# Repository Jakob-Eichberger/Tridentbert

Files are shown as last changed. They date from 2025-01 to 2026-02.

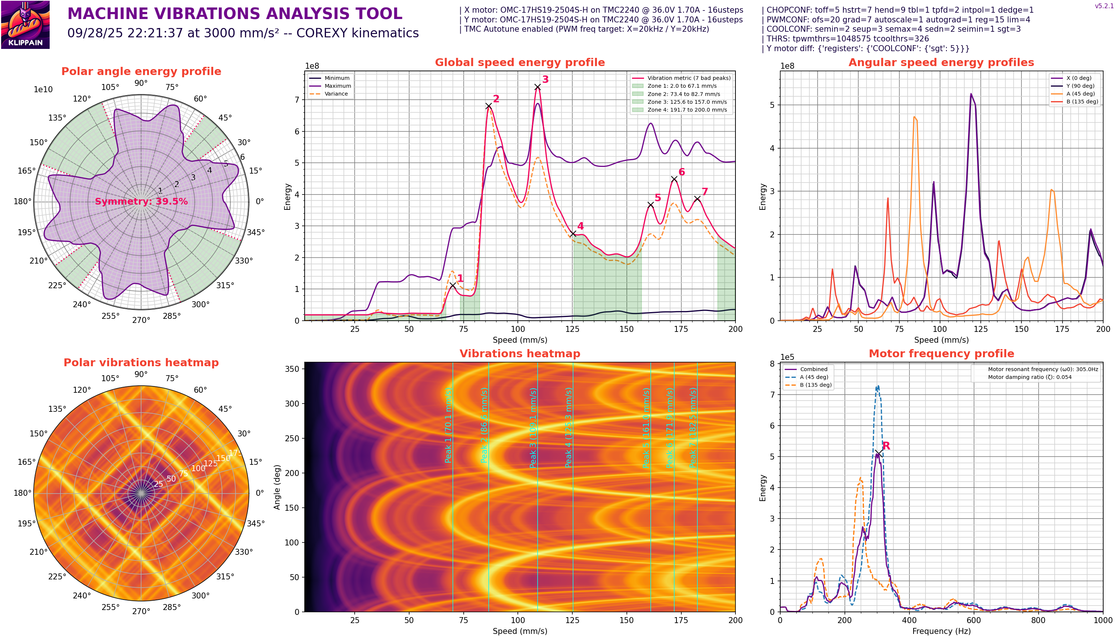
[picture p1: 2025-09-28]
ShakeTune_results/vibrations/vibrationsprofile_20250928_222136.png

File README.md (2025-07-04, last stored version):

# Tridentbert
Tridentbert is my take on a 300 x 300 x 250mm Voron Trident, a popular open source diy 3d printer, changed with all the best mods making this one of the most capable 3d printer on the market today.



# Improvements over a stock Voron Trident
> [!CAUTION]
> This design is based on and will only work with Takeoff toolhead and Chube hotend. This is because of the changed gantry height so that Takeoff wont hit one of the z leadscrews.
> **Using a more standard Voron toolhead might result in the nozzle not beeing able to reach the bed!**

* 4040 based 20 extrusions for increased frame rigidity, which helps when printing at high speed and with high belt tension.
* 6mm aluminium panels all around the machine, to increase rigidity even more.
* Monolith 9mm AWD sheet metal gantry, which is the best gantry design currently on the market.
* Using Takeoff toolhead with Chube, Beacon probe and a CNC Sherpa Mini extruder from Fystec for maximum extrusion performance.
* Z stepper motors mounted directly to the bottom aluminum panel for easy mounting.
* Electronics are mounted on the side for super easy maintenance.

# License
Since this printers frame is derived from a Voron Trident, the Voron Trident License applies to the frame only. The panels and electronics sidepack are off my own design and are licensed under `Attribution-NonCommercial-ShareAlike 4.0 International`. This project does not alter nor try to alter the licencse of used mods.
* Monolith gantry: https://github.com/CloakedWayne/Monolith_Gantry_V2-VT?tab=License-1-ov-file#readme
* Takeoff toolhead: https://github.com/Kizime123/Takeoff-Toolhead?tab=GPL-3.0-1-ov-file#readme
* Voron Trident: https://github.com/VoronDesign/Voron-Trident

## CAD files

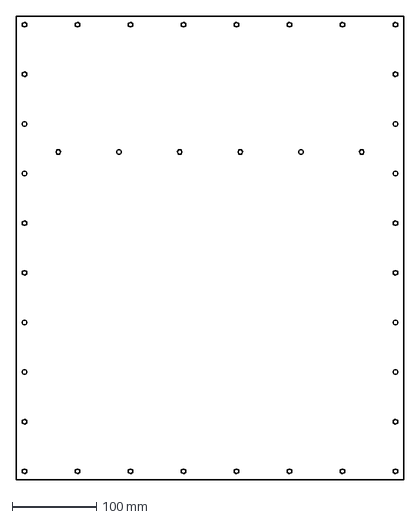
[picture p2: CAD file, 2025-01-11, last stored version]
DXF/Panel_Side.dxf
460.0 x 550.0 mm

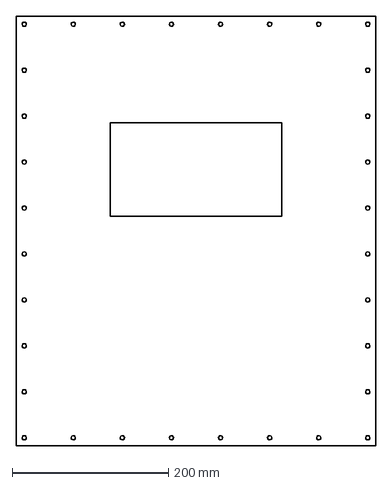
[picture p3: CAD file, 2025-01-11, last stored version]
DXF/Panel_Door.dxf
460.0 x 550.0 mm

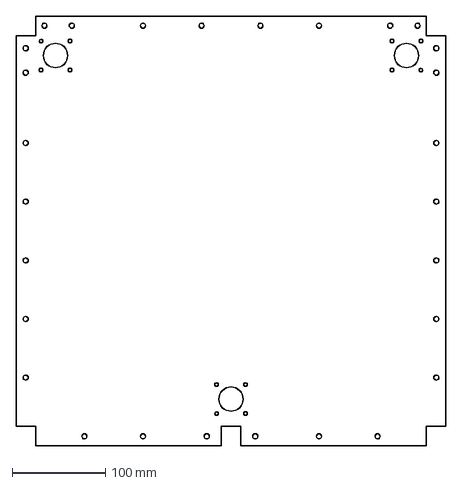
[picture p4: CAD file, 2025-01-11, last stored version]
DXF/Panel_Bottom.dxf
460.0 x 460.0 mm

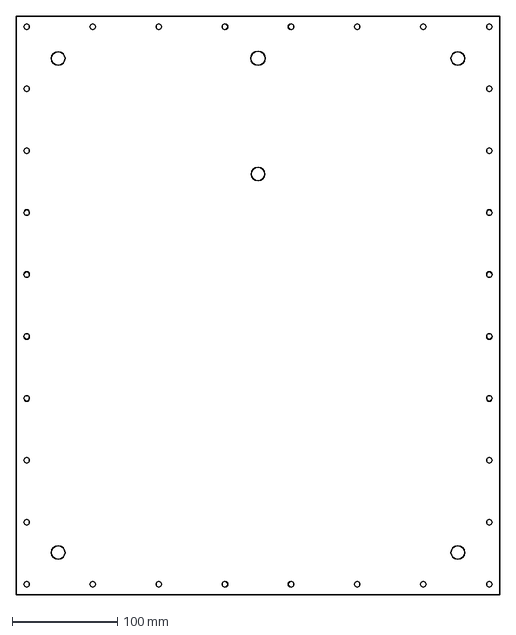
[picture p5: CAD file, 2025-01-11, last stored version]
DXF/Panel_Back.dxf
460.0 x 550.0 mm

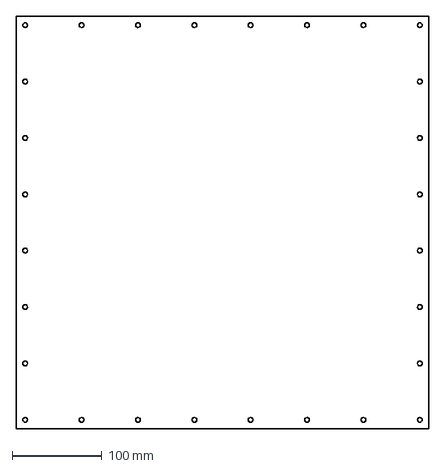
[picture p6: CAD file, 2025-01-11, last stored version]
DXF/Panel_Top.dxf
460.0 x 460.0 mm

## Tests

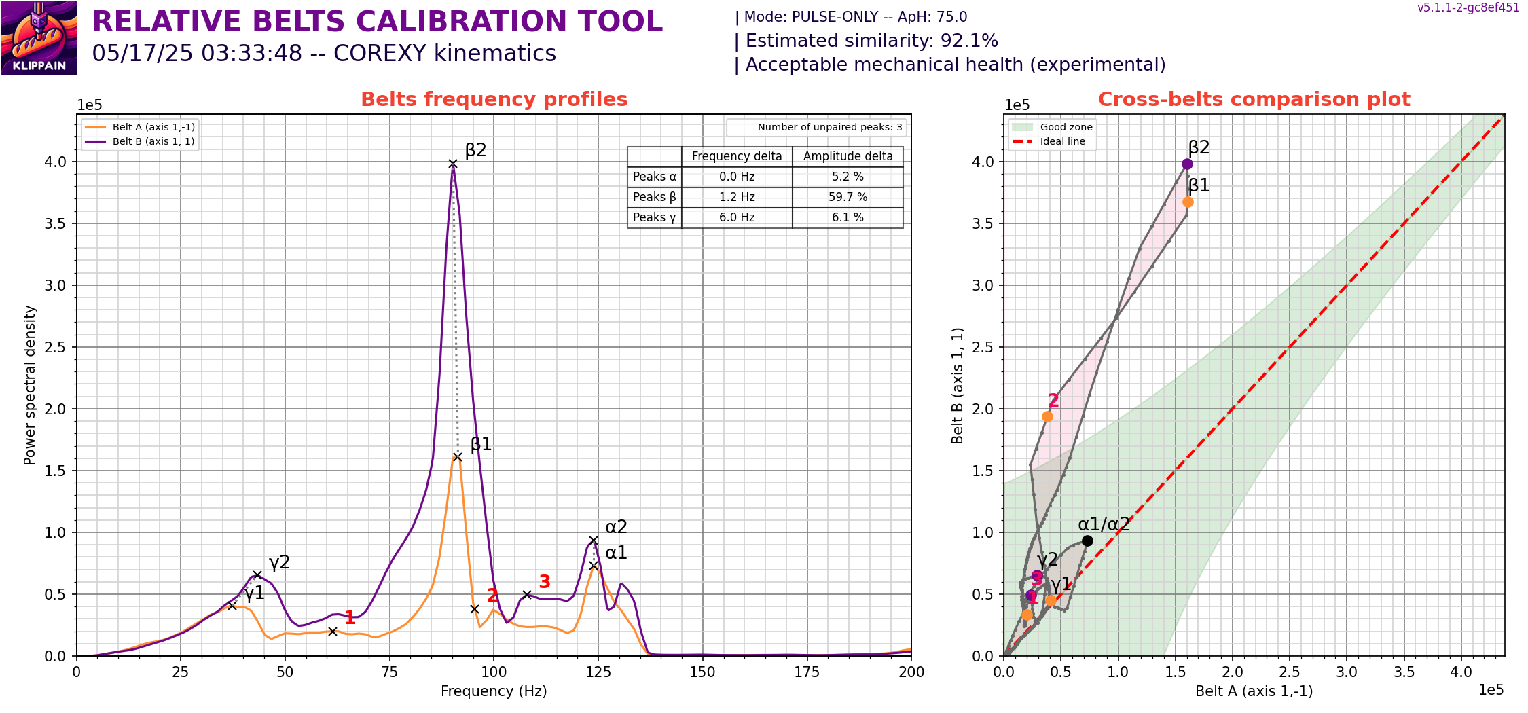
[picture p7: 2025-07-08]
ShakeTune_results/belts/beltscomparison_20250517_033347.png

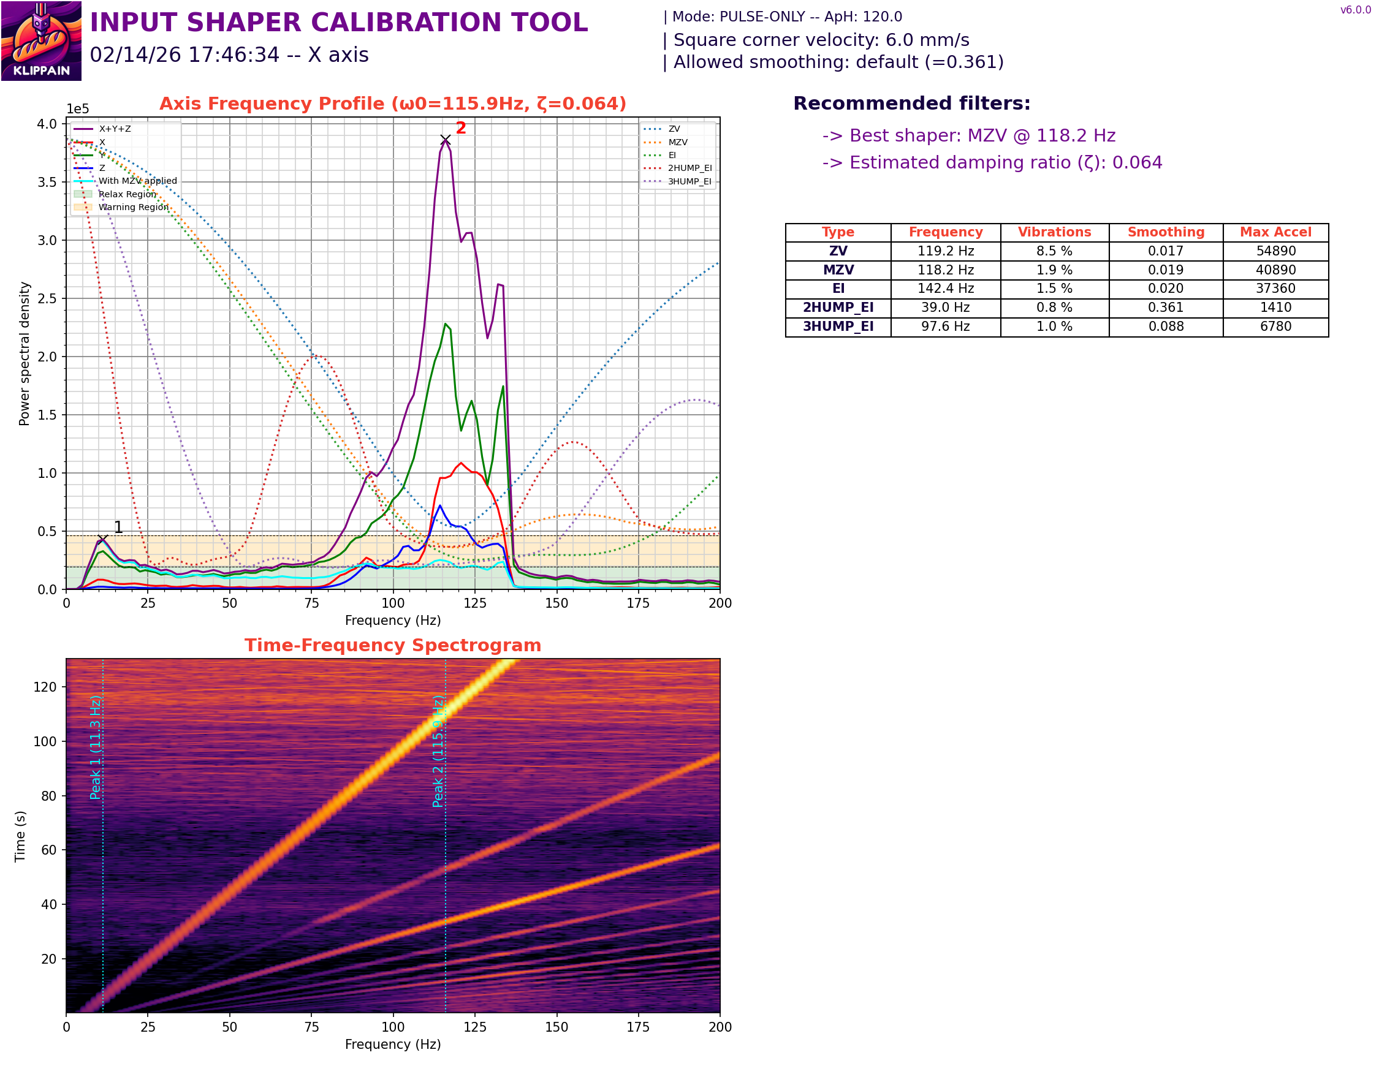
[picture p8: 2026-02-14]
ShakeTune_results/input_shaper/inputshaper_20260214_174632_axis_X.png

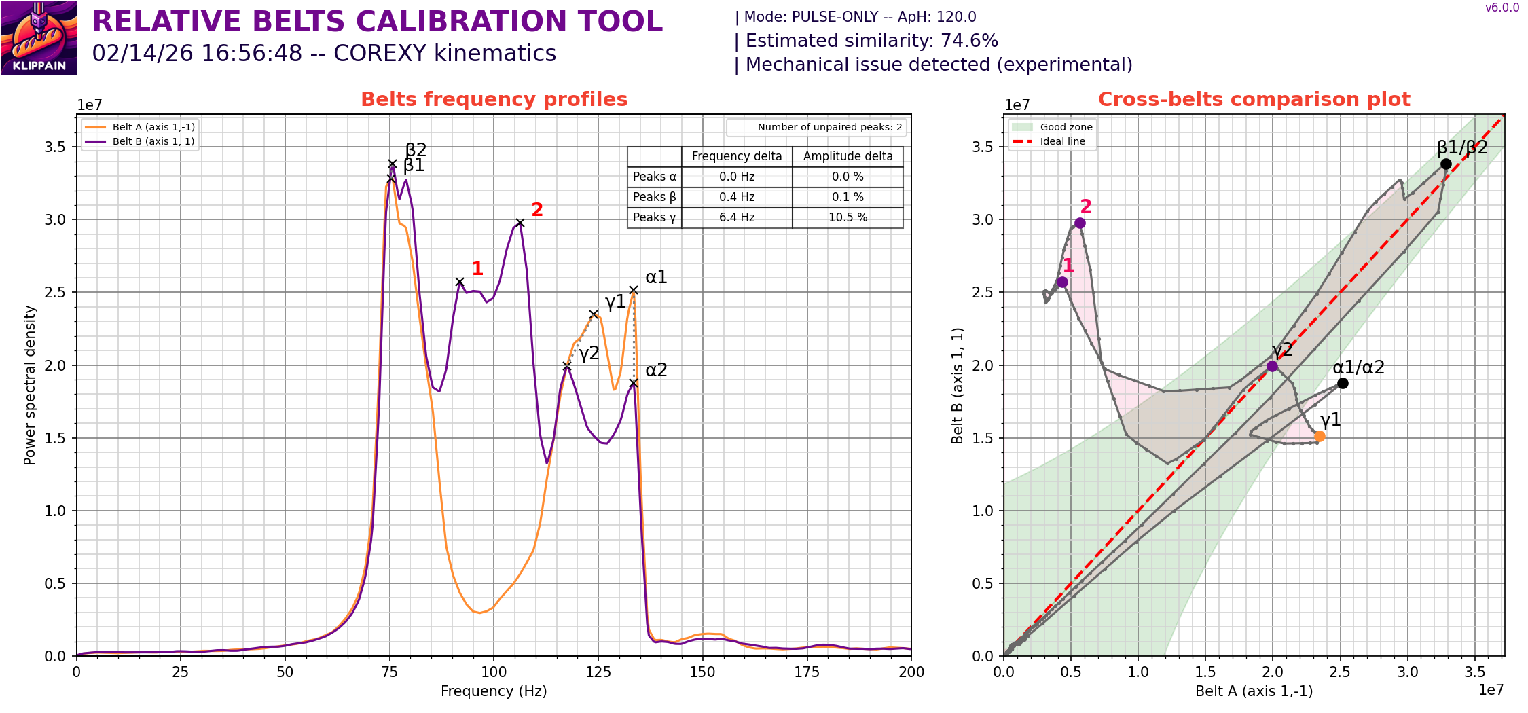
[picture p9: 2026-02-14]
ShakeTune_results/belts/beltscomparison_20260214_165647.png

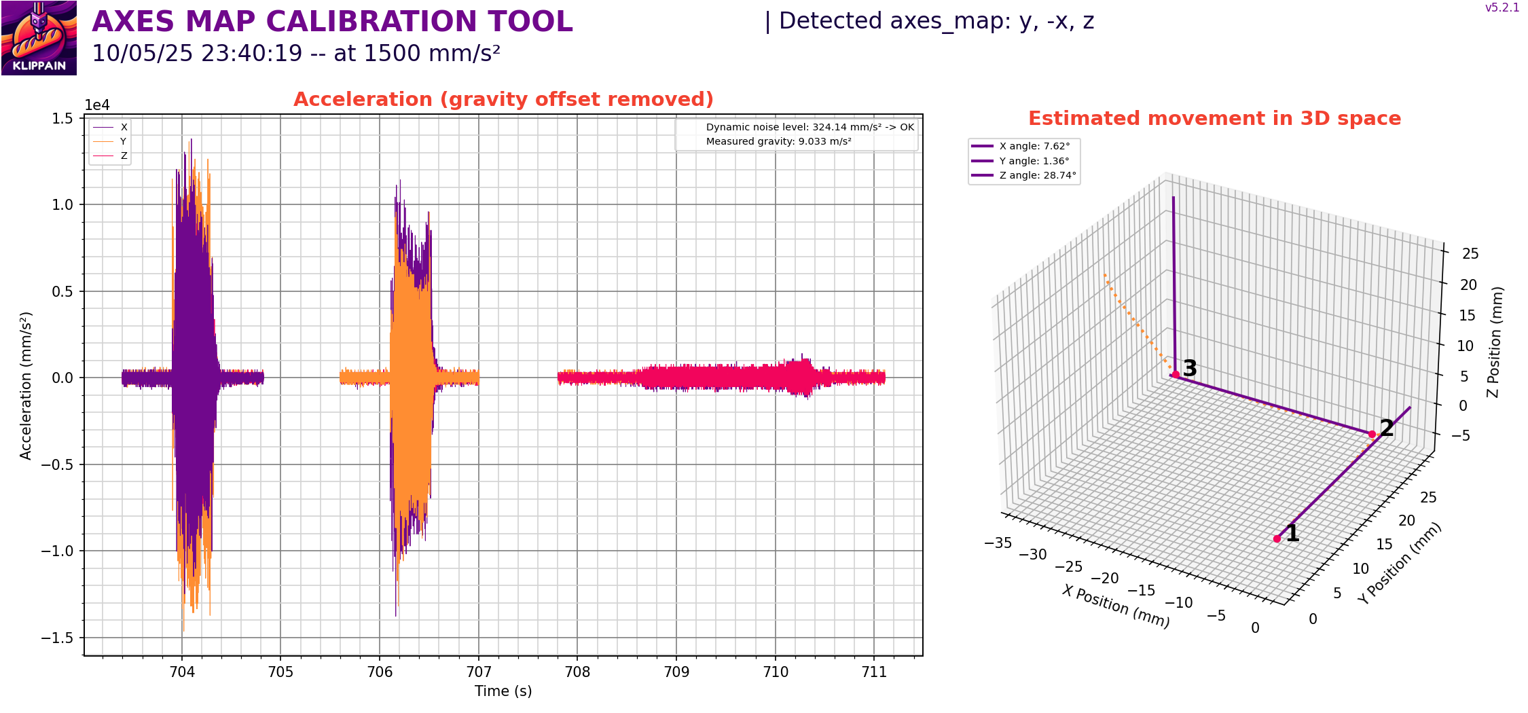
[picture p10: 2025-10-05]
ShakeTune_results/axes_map/axesmap_20251005_234019.png

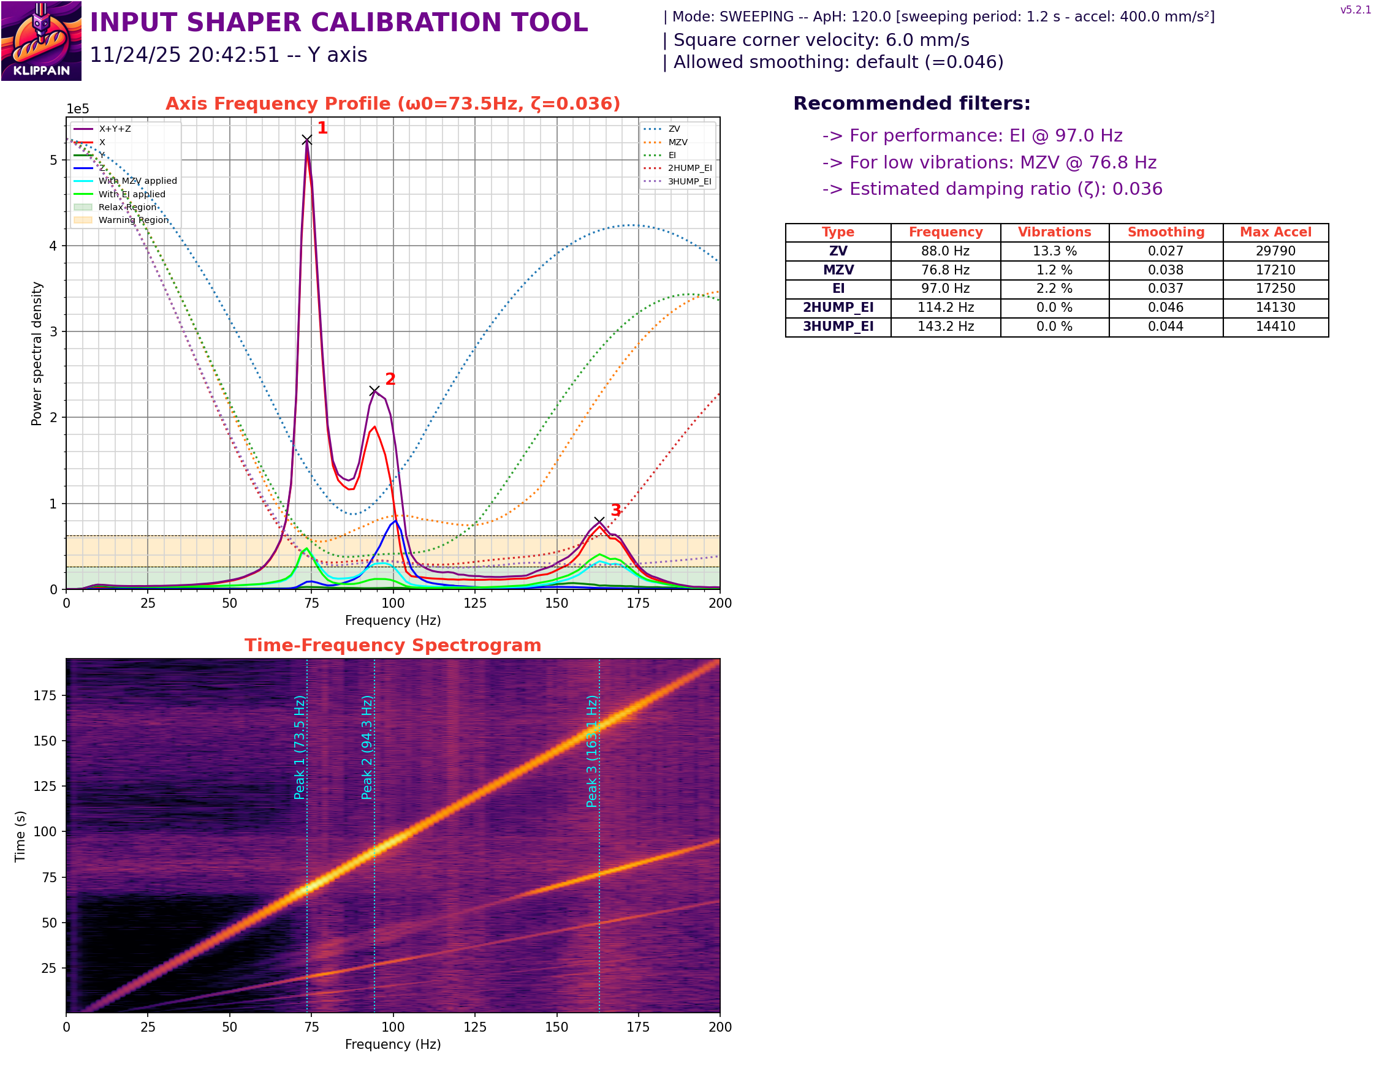
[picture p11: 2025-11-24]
ShakeTune_results/input_shaper/inputshaper_20251124_203850_axis_Y.png

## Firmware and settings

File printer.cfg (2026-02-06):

#[include mainsail.cfg]
[include macro.cfg]
[include Line_Purge.cfg]
[include KAMP_Settings.cfg]
[include Smart_Park.cfg]
[include TEST_SPEED.cfg]
[include config_backup.cfg]
[include macro_thermal_expansion_compensation.cfg]
[mcu]
serial: /dev/serial/by-id/usb-Klipper_stm32f446xx_440035001550535556323420-if00
restart_method: command

[mcu therm]
serial: /dev/serial/by-id/usb-Klipper_stm32f042x6_048021000F4330344E333720-if00
restart_method: command
#####################################################################
#   Extruder
#####################################################################

[virtual_sdcard]
path: ~/printer_data/gcodes
on_error_gcode: CANCEL_PRINT

[pause_resume]

[display_status]

[respond]

[auto_speed]

[save_variables]
filename: ~/printer_data/config/variables.txt

[printer]
kinematics: corexy
max_velocity: 600
max_accel: 20000
max_z_velocity: 15
max_z_accel: 45
square_corner_velocity: 6.0

[extruder]
enable_pin: !PE0
step_pin: PE6
dir_pin: PA14                                                      # Add ! if moving opposite direction
full_steps_per_rotation: 200                                       # Set to 200 for LDO 1.8° stepper motor, and set to 400 for OMC(StepperOnline) 0.9° stepper motor

#wwbmg
rotation_distance:  22.23
gear_ratio: 50:10

#G2A
#rotation_distance:  47.088                                           # See calibrating rotation_distance on extruders doc
#gear_ratio: 9:1                                                    # For Mini Afterburner

microsteps: 16


nozzle_diameter: 0.500
filament_diameter: 1.750

heater_pin: PA2                                                  
sensor_type: PT1000    

sensor_pin: therm:PA5
min_temp: 0
max_temp: 500
min_extrude_temp: 170
max_extrude_only_distance: 300
pressure_advance: 0.028
pressure_advance_smooth_time: 0.020000
max_extrude_cross_section: 50

#heater_power: 120
# MPC settings
#control: mpc
#cooling_fan: fan
#filament_diameter: 1.75
#filament_density: 1.20
#filament_heat_capacity: 1.8 

#control: pid
#pid_kp: 55.642
#pid_ki: 3.041
#pid_kd: 254.560
#pid_version: 1
#pid_target: 105.00
#pid_tolerance: 0.0200

#[verify_heater extruder]
#max_error: 120 # double if needed
#check_gain_time: 60 #default for extruder is 20, 60 for bed heater. increase for weak heaters. 
#hysteresis: 5 #default is 5, this is the maximum allowable deviation from setpoint. increase during PID tuning. 
#heating_gain: 1.5 #default is 2. increase this for very fast heaters, decrease this for weak ones.

[tmc2240 extruder]
cs_pin: PD3
spi_bus: spi1
interpolate: False
run_current: 0.6
stealthchop_threshold: 0       
rref: 12000

#####################################################################
#   Motors
#####################################################################

# Driver3
[stepper_x1]
enable_pin: !PA0
step_pin: PG4
dir_pin: PC1
microsteps: 16
rotation_distance: 40

[tmc2240 stepper_x1]
cs_pin: PC7
spi_bus: spi1
rref: 12000
run_current: 1.7
stealthchop_threshold: 0


# Driver4
[stepper_x]
enable_pin: !PG2
step_pin: PF9
dir_pin: PF10
microsteps: 16
rotation_distance: 40

endstop_pin: tmc2240_stepper_x:virtual_endstop
position_endstop: 300
position_max: 300
homing_speed: 100
homing_retract_dist: 200
min_home_dist: 40
homing_positive_dir: true
use_sensorless_homing: true

[tmc2240 stepper_x]
cs_pin: PF2
spi_bus: spi1
rref: 12000
stealthchop_threshold: 0
run_current: 1.7

home_current: 0.5
diag0_pin: ^!PG12
#driver_SGT: 3

# Driver5
[stepper_y1]
enable_pin: !PF1
step_pin: PC13
dir_pin: PF0
microsteps: 16
rotation_distance: 40

[tmc2240 stepper_y1]
cs_pin: PE4
spi_bus: spi1
rref: 12000
stealthchop_threshold: 0
run_current: 1.7


# Driver6
[stepper_y] 
enable_pin: !PD4
step_pin: PE2
dir_pin: PE3
microsteps: 16
rotation_distance: 40
endstop_pin: tmc2240_stepper_y:virtual_endstop
position_endstop: 267
position_max: 267
homing_speed: 100
homing_retract_dist: 60
min_home_dist: 40
homing_positive_dir: true
use_sensorless_homing: true

[tmc2240 stepper_y]
cs_pin: PE1
spi_bus: spi1
rref: 12000
stealthchop_threshold: 0
run_current: 1.7

home_current: 0.5
diag0_pin: ^!PG14
#driver_SGT: 3

# Driver0
[stepper_z]
enable_pin: !PF14
step_pin: PF13
dir_pin: !PF12
microsteps: 16
rotation_distance: 8
endstop_pin: PG10
position_endstop: 00
position_max: 250
position_min: -5

[tmc2240 stepper_z]
cs_pin: PC4
spi_bus: spi1
rref: 12000
stealthchop_threshold: 999999
run_current: 0.800

# Driver1
[stepper_z1]
enable_pin: !PF15
step_pin: PG0
dir_pin: !PG1
microsteps: 16
rotation_distance: 8
endstop_pin: PG10

[tmc2240 stepper_z1]
cs_pin: PD11
spi_bus: spi1
rref: 12000
stealthchop_threshold: 999999
run_current: 0.800

# Driver2
[stepper_z2]
enable_pin: !PG5
step_pin: PF11
dir_pin: !PG3
microsteps: 16
rotation_distance: 8

[tmc2240 stepper_z2]
cs_pin: PC6
spi_bus: spi1
rref: 12000
stealthchop_threshold: 999999
run_current: 0.800

[autotune_tmc stepper_x]
motor: omc-17hs19-2504s-h
sgt: 4
voltage: 36

[autotune_tmc stepper_x1]
motor: omc-17hs19-2504s-h
voltage: 36

[autotune_tmc stepper_y]
motor: omc-17hs19-2504s-h
sgt: 5
voltage: 36

[autotune_tmc stepper_y1]
motor: omc-17hs19-2504s-h
voltage: 35

#####################################################################
#   Bed Mesh + Probe
#####################################################################

[beacon]
serial: /dev/serial/by-id/usb-Beacon_Beacon_RevH_7A4B73935154354D38202020FF0A1731-if00
is_non_critical: True
home_method: contact
home_method_when_homed: contact
home_autocalibrate: unhomed
x_offset: -23
y_offset: 0
mesh_main_direction: x
mesh_runs: 2
speed: 3000
lift_speed: 250
home_xy_position: 140,140 ; Also change the position in zero_reference_position
home_xy_move_speed: 300
home_z_hop_speed: 50
home_z_hop: 15
home_y_before_x: true
contact_max_hotend_temperature: 175

[bed_mesh]
speed: 400
horizontal_move_z: 15
mesh_min: 35, 35
mesh_max: 230, 230
probe_count: 25, 25
mesh_pps: 3, 3 #specifies how many points to interpolate for each segment along the X and Y axes
algorithm: bicubic
zero_reference_position: 140,140 ; Also change the value in beacon -> home_xy_position

[z_tilt]
z_positions:
   -50, 18
   150, 348
   350, 18
points:
   30, 5
   150, 212
   270, 5
speed: 200
horizontal_move_z: 20

adaptive_horizontal_move_z: True

retries: 5
retry_tolerance: 0.01
use_probe_xy_offsets: true
  
#####################################################################
#   Resonance
#####################################################################

[input_shaper]
shaper_freq_x: 134.2
#shaper_type_x: ei
damping_ratio_x: 0.038

shaper_freq_y: 78
#shaper_type_y: ei
damping_ratio_y: 0.039

shaper_type: ei

[shaketune]

[resonance_tester]
accel_chip: beacon
probe_points: 150, 150, 20
accel_per_hz: 120
sweeping_accel: 400
sweeping_period: 0
max_freq: 200
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

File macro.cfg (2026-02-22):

#####################################################################
#   GUI Macros
#####################################################################

[gcode_macro Force_Lower_Bed]
gcode:
    {% set zChange = params.zChange|default(20)|int %}
    G90
    SET_KINEMATIC_POSITION Z=0 X=150 Y=150
    G0  Z{zChange} F5000
    M84
    
#####################################################################
#   Automatic Macros
#####################################################################

[gcode_macro PRINT_START]
variable_enclosed_temp_min: 45
gcode:
    BACKUP_CFG
    {% set bedtemp = params.BED|int %}
    {% set hotendtemp = params.HOTEND|int %}
    {% set material = params.FILAMENT_TYPE | string %}
    {% set chambertemp = params.CHAMBER_TEMP | int %}

    {% set nozzleHomingTemperature = printer.configfile.settings['beacon'].contact_max_hotend_temperature - 5 %} ; remove 5C from homing temperature to remove risk of beacon panik if extruder temperature fluctuates slightly.
    
    _SET_MPC_MATERIAL MATERIAL={material}

    SET_HEATER_TEMPERATURE HEATER=chamber_heater TARGET={chambertemp} ; Set chamber heater to temperature without waiting
    SET_HEATER_TEMPERATURE HEATER=extruder TARGET=0 ; Set nozzle to 0 to avoid burning filament in the nozzle.
    SET_HEATER_TEMPERATURE HEATER=heater_bed TARGET={bedtemp} ; set bed to printing temperature without waiting
    
    {% if chambertemp != 0 %}
      RESPOND TYPE=command MSG='Waiting for chamber to reach temperature.'
      TEMPERATURE_WAIT SENSOR="heater_generic chamber_heater" MINIMUM={chambertemp-5}
      RESPOND TYPE=command MSG='Chamber reached temperature.'
    {% endif %}

    SET_HEATER_TEMPERATURE HEATER=extruder TARGET={nozzleHomingTemperature} ; set nozzle to homing temperature without waiting
    M190 S{bedtemp} ; set correct bed temp with waiting
    M109 S{nozzleHomingTemperature} ; set nozzle to homing temp with waiting
    
    {% if "xy" not in printer.toolhead.homed_axes %}
       G28 X Y ; home only x and y
    {% endif %}

    CLEAN_NOZZLE ; clean nozzle
    {% if "z" not in printer.toolhead.homed_axes %}
      G28 Z METHOD=CONTACT CALIBRATE=0 ; home z without calibration
    {% endif %}
    
    z_tilt_adjust ; run z tilt adjust
    CLEAN_NOZZLE ; clean the nozzle one more time
    G28 Z METHOD=CONTACT CALIBRATE=1
    
    M400 ; clear buffer 
    #SYNC_MOTORS
    
    BED_MESH_CALIBRATE ADAPTIVE=1
    
    SMART_PARK 
    M109 S{hotendtemp} ; set nozzle to target temp
    G90 ; absolute positioning
    M83 ; Use relative distances for extrusion
    CLEAR_PAUSE ; required to reset the Pause flag correctly https://www.klipper3d.org/G-Codes.html?h=clear_pause#clear_pause
   
    ;set nozzle thermal expansion offset
    _BEACON_SET_NOZZLE_TEMP_OFFSET 

    #SAVE_GCODE_STATE NAME=BeforePurge  
    #CLEAN_NOZZLE
    #RESTORE_GCODE_STATE NAME=BeforePurge MOVE=1 MOVE_SPEED=300   ; clean the nozzle in case of any long strings
    
    LINE_PURGE

  
[gcode_macro PRINT_END]
gcode:
    {% set z_Position = printer.toolhead.position.z + 10 %}
    {% set y_Position = printer.toolhead.axis_maximum.y - 40 | float %}
    {% set x_Position = printer.toolhead.axis_minimum.x + 40 | float %}
    
    M400 ; wait for buffer to clear
    M107 ; turn off fan    
    TURN_OFF_HEATERS
    BED_MESH_CLEAR
    CLEAR_PAUSE
    
    # reset nozzle thermal expansion offset
    _BEACON_REMOVE_NOZZLE_TEMP_OFFSET
    _BEACON_SET_NOZZLE_TEMP_OFFSET RESET=True

    G90 ; absolute positioning
    {% if z_Position < printer.toolhead.axis_maximum.z %}
         G0 Z{z_Position} F3600 ; lower bed if possible
    {% endif %}
    G0 X{x_Position} Y{y_Position} F3600 ; park nozzle at rear

[gcode_macro WEAR_IN_BELTS]
gcode:
    {% set maxX = printer.toolhead.axis_maximum.x - 5 %}
    {% set maxY = printer.toolhead.axis_maximum.y - 5 %}
    {% set minX = printer.toolhead.axis_minimum.x + 5 %}
    {% set minY = printer.toolhead.axis_minimum.y + 5 %}
    G90
    
    G1 X{minX} Y{minY} F15000 ; front left
    G1 X{maxX} Y{minY} F15000 ; front right
    G1 X{maxX} Y{maxY} F15000 ; back right
    G1 X{minX} Y{maxY} F15000 ; back left
    G1 X{minX} Y{minY} F15000 ; front left
    G1 X{maxX} Y{maxY} F15000 ; back right
    G1 X{minX} Y{maxY} F15000 ; back left
    G1 X{maxX} Y{minY} F15000 ; front right
    G1 X{minX} Y{minY} F15000 ; front left
    G1 X{maxX/2} Y{maxY/2} F15000 ; front left

     
[gcode_macro PAUSE]
rename_existing: BASE_PAUSE
gcode:
    # Parameters
    {% set z = params.Z|default(10)|int %}                                                   ; z hop amount

    {% if printer['pause_resume'].is_paused|int == 0 %}
        SET_GCODE_VARIABLE MACRO=RESUME VARIABLE=zhop VALUE={z}                              ; set z hop variable for reference in resume macro
        SET_GCODE_VARIABLE MACRO=RESUME VARIABLE=etemp VALUE={printer['extruder'].target}    ; set hotend temp variable for reference in resume macro

        SAVE_GCODE_STATE NAME=PAUSE                                                          ; save current print position for resume
        BASE_PAUSE                                                                           ; pause print
        {% if (printer.gcode_move.position.z + z) < printer.toolhead.axis_maximum.z %}       ; check that zhop doesn't exceed z max
            G91                                                                              ; relative positioning
            G1 Z{z} F900                                                                     ; raise Z up by z hop amount
        {% else %}
            { action_respond_info("Pause zhop exceeds maximum Z height.") }                  ; if z max is exceeded, show message and set zhop value for resume to 0
            SET_GCODE_VARIABLE MACRO=RESUME VARIABLE=zhop VALUE=0
        {% endif %}
        G90                                                                                  ; absolute positioning
        G1 X{printer.toolhead.axis_maximum.x/2} Y{printer.toolhead.axis_minimum.y+5} F6000   ; park toolhead at front center
        SAVE_GCODE_STATE NAME=PAUSEPARK                                                      ; save parked position in case toolhead is moved during the pause (otherwise the return zhop can error)
        M104 S0                                                                              ; turn off hotend
        SET_IDLE_TIMEOUT TIMEOUT=43200                                                       ; set timeout to 12 hours
    {% endif %}

[gcode_macro RESUME]
rename_existing: BASE_RESUME
variable_zhop: 0
variable_etemp: 0
gcode:
    # Parameters
    {% set e = params.E|default(2.5)|int %}                                          ; hotend prime amount (in mm)

    {% if printer['pause_resume'].is_paused|int == 1 %}
        SET_IDLE_TIMEOUT TIMEOUT={printer.configfile.settings.idle_timeout.timeout}  ; set timeout back to configured value
        {% if etemp > 0 %}
            M109 S{etemp|int}    
        {% endif %}
      
        RESTORE_GCODE_STATE NAME=PAUSEPARK MOVE=1 MOVE_SPEED=300                     ; go back to parked position in case toolhead was moved during pause (otherwise the return zhop can error)
        G91                                                                          ; relative positioning
        M83                                                                          ; relative extruder positioning

        {% if printer[printer.toolhead.extruder].temperature >= printer.configfile.settings.extruder.min_extrude_temp %}
            G1 E{e} F900      
        {% endif %}
       
        CLEAN_NOZZLE

        G1 Z{zhop * -1} F900  ; lower Z back down

        RESTORE_GCODE_STATE NAME=PAUSE ;MOVE=1 MOVE_SPEED=300                          ; restore position
        BASE_RESUME                                                                  ; resume print
    {% endif %}

[gcode_macro CANCEL_PRINT]
rename_existing: BASE_CANCEL_PRINT
gcode:

    SET_IDLE_TIMEOUT TIMEOUT={printer.configfile.settings.idle_timeout.timeout} ; set timeout back to configured value
    CLEAR_PAUSE
    #SDCARD_RESET_FILE
    PRINT_END
    BASE_CANCEL_PRINT
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

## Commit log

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2025-07-08 Autocommit from 2025-07-08 23:14:57
    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
    [config_backup.cfg, printer.cfg]
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2025-07-09 Autocommit from 2025-07-10 00:23:13
    Klipper version: v0.12.0-715-g91fd6480
    Moonraker version: v0.9.3-87-g06cdffa
    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
    [AFC.cfg, AFC_Hardware.cfg, AFC_Lite.cfg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]
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2025-07-19 Autocommit from 2025-07-19 18:32:42
    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
    [macro.cfg]
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2025-07-19 Autocommit from 2025-07-19 18:42:39
    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
    [macro.cfg, printer.cfg]
2025-07-19 Autocommit from 2025-07-19 18:52:30
    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
    [macro.cfg]
2025-07-19 Autocommit from 2025-07-19 18:53:13
    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
    [macro.cfg]
2025-07-19 Autocommit from 2025-07-19 18:53:49
    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
    [macro.cfg]
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2025-07-19 Autocommit from 2025-07-19 20:44:18
    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
    [macro.cfg]
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2025-07-19 Autocommit from 2025-07-19 20:45:41
    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
    [macro.cfg]
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2025-07-19 Autocommit from 2025-07-19 21:05:05
    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
    [KAMP_Settings.cfg, macro.cfg]
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2025-07-20 Autocommit from 2025-07-20 16:07:46
    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
    [printer.cfg]
2025-07-20 Autocommit from 2025-07-20 16:28:34
    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
    [macro.cfg]
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2025-07-20 Autocommit from 2025-07-20 22:55:43
    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
    [macro.cfg]
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2025-07-30 Autocommit from 2025-07-30 23:56:25
    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
    [printer.cfg]
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2025-08-01 Autocommit from 2025-08-01 13:38:51
    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
    [printer.cfg]
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2025-08-03 Autocommit from 2025-08-03 15:40:59
    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
    [printer.cfg]
2025-08-03 Autocommit from 2025-08-03 15:56:02
    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
    [macro.cfg, printer.cfg]
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2025-08-06 Autocommit from 2025-08-06 03:35:52
    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
    [printer.cfg]
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2025-08-06 Autocommit from 2025-08-06 18:08:46
    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
    [macro.cfg]
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2025-08-06 Autocommit from 2025-08-06 20:38:39
    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
    [macro.cfg]
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2025-08-09 Autocommit from 2025-08-09 18:09:18
    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
    [printer.cfg]
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2025-08-09 Autocommit from 2025-08-09 18:27:52
    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
    [printer.cfg]
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2025-08-12 Autocommit from 2025-08-12 23:47:55
    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
    [printer-20250809_211029.cfg, printer-20250809_214056.cfg]
2025-08-13 Autocommit from 2025-08-13 16:17:50
    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
    [printer.cfg]
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2025-08-13 Autocommit from 2025-08-13 21:51:30
    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
    [printer.cfg]
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2025-08-14 Autocommit from 2025-08-14 13:21:30
    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
    [printer.cfg]
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2025-08-14 Autocommit from 2025-08-14 13:45:26
    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
    [printer.cfg]
2025-08-14 Autocommit from 2025-08-14 13:51:09
    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
    [printer.cfg]
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2025-08-17 Autocommit from 2025-08-17 21:29:51
    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
    [printer.cfg]
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2025-08-18 Autocommit from 2025-08-18 10:46:15
    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
    [macro.cfg]
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2025-08-18 Autocommit from 2025-08-18 14:59:24
    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
    [macro.cfg]
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2025-08-18 Autocommit from 2025-08-18 18:26:56
    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
    [macro.cfg]
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2025-08-21 Autocommit from 2025-08-21 21:26:16
    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
    [printer.cfg]
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2025-08-22 Autocommit from 2025-08-22 16:33:34
    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
    [printer-20250821_224942.cfg]
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2025-08-24 Autocommit from 2025-08-24 23:36:51
    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
    [AFC.cfg, AFC_Hardware.cfg, AFC_Macro_Vars.cfg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]
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2025-08-25 Autocommit from 2025-08-25 21:06:25
    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
    [macro.cfg]
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2025-08-25 Autocommit from 2025-08-25 21:23:26
    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
    [printer.cfg]
2025-08-25 Autocommit from 2025-08-25 21:31:51
    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
    [macro.cfg]
2025-08-27 Autocommit from 2025-08-27 20:06:30
    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
    [AFC_Macro_Vars.cfg, macro.cfg, printer.cfg]
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2025-08-28 Autocommit from 2025-08-28 20:16:20
    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
    [printer.cfg]
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2025-08-28 Autocommit from 2025-08-28 22:13:31
    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
    [macro.cfg]
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2025-08-29 Autocommit from 2025-08-29 12:11:38
    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
    [macro.cfg]
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2025-09-06 Autocommit from 2025-09-06 13:26:27
    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
    [printer.cfg]
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2025-09-06 Autocommit from 2025-09-06 14:42:14
    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
    [macro.cfg]
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2025-09-07 Autocommit from 2025-09-07 21:34:27
    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
    [macro.cfg, printer.cfg]
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2025-09-07 Autocommit from 2025-09-07 22:22:31
    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
    [printer.cfg]
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2025-09-09 Autocommit from 2025-09-09 23:43:47
    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
    [printer.cfg]
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2025-09-11 Autocommit from 2025-09-11 23:41:18
    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
    [printer.cfg]
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2025-09-21 Autocommit from 2025-09-21 20:36:32
    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
    [macro.cfg]
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2025-09-28 Autocommit from 2025-09-28 20:23:32
    Klipper version: v0.12.0-725-g1933e019
    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
    [printer.cfg]
2025-09-28 Autocommit from 2025-09-28 23:15:36
    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
    [printer.cfg]
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2025-09-30 Autocommit from 2025-09-30 10:35:16
    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
    [printer.cfg]
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2025-10-03 Autocommit from 2025-10-04 00:11:27
    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
    [printer.cfg]
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2025-10-05 Autocommit from 2025-10-05 20:23:01
    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
    [printer.cfg]
2025-10-05 Autocommit from 2025-10-05 20:46:14
    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
    [printer.cfg]
2025-10-05 Autocommit from 2025-10-05 21:51:27
    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
    [printer.cfg]
2025-10-05 Autocommit from 2025-10-05 22:56:41
    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
    [printer.cfg]
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2025-10-05 Autocommit from 2025-10-06 00:00:32
    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
    [printer-20251005_234118.cfg]
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2025-10-11 Autocommit from 2025-10-11 19:52:55
    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
    [macro.cfg]
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2025-10-14 Autocommit from 2025-10-14 18:13:33
    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
    [macro.cfg, printer.cfg]
2025-10-14 Autocommit from 2025-10-14 18:32:16
    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
    [printer.cfg]
2025-10-14 Autocommit from 2025-10-14 19:31:07
    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
    [printer.cfg]
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2025-10-14 Autocommit from 2025-10-14 23:29:13
    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
    [printer.cfg]
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2025-10-15 Autocommit from 2025-10-15 23:17:37
    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
    [printer.cfg]
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2025-10-18 Autocommit from 2025-10-19 00:37:23
    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
    [printer.cfg]
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
